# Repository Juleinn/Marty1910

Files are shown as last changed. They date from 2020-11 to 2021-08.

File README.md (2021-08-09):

# Marty 1910 bluetooth interface firmware

This repository stores the firmware for getting old marty 1910 phones back to life with a ag1171 and bm64 modules (SLIC and Bluetooth modules).

- Vidéo :   
Marty 1910 restoration video (https://www.youtube.com/watch?v=Hyl_VwFzOQQ)
- Hackaday.io : [Marty 1910 adapter](https://hackaday.io/project/181056-marty-1910-magneto-phone-bluetooth-adapter)

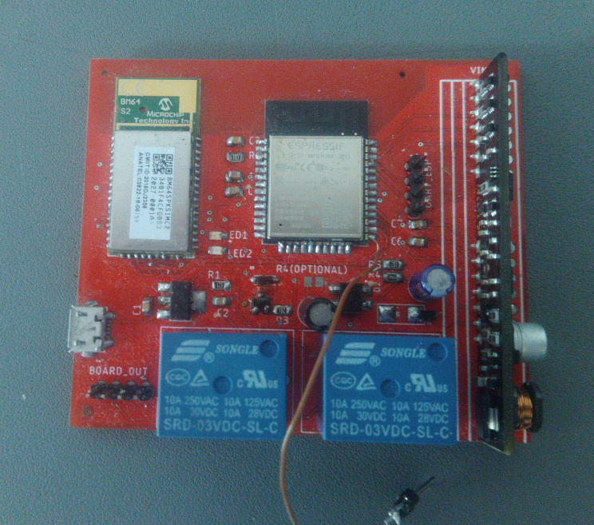
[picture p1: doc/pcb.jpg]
PCB


## Contents
<!-- vim-markdown-toc GitLab -->

* [requirements](#requirements)
* [Configuring the BM64 module](#configuring-the-bm64-module)
* [directory structure](#directory-structure)
* [Firmware description](#firmware-description)

<!-- vim-markdown-toc -->

## requirements
- esp-idf : https://docs.espressif.com/projects/esp-idf/en/latest/esp32/get-started/index.html#installation-step-by-step
- ftdi (for flashing and install)

## Configuring the BM64 module
The BM64 modules requires configuration prior to using it. The configuration process is detailed here : https://github.com/danjulio/blue_pot#bm64-configuration, and this project works with the exact same BM64 configuration as the Blue POT project.

## directory structure
```bash
tree main
main
├── ag1171_driver.c // SLIC driver, including RING signal generation & hangup detection
├── ag1171_driver.h
├── bm64_driver.c // BM64 driver : incomming call events, place calls, ...
├── bm64_driver.h
├── bm64_strings.h
├── CMakeLists.txt
├── component.mk
├── firmware_main.c // main logic
├── line.c  // cranking detection and line relay driving
└── line.h
```

```bash
tree hardware
hardware
├── bluetooth.brd # PCB design
├── bluetooth.csv # list of components
└── bluetooth.sch # schematic
```

## Firmware description

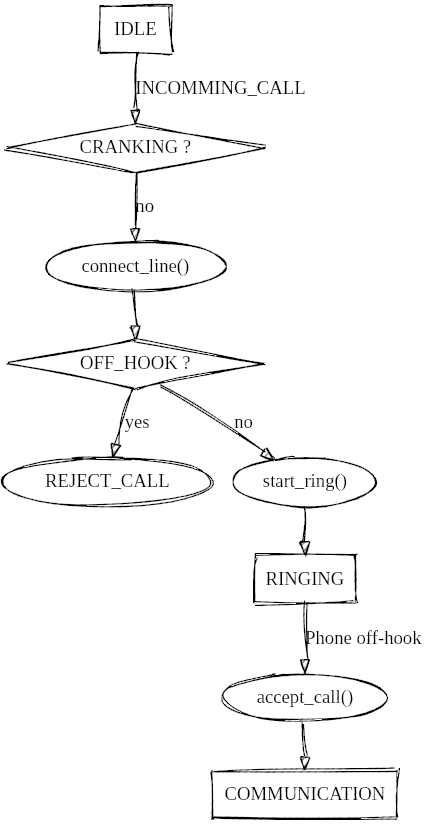
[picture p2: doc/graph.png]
firmware_flowchart


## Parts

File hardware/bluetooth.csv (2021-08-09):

Part | Value | Device | Package | Description | CENTROID_NOT_SPECIFIED | DATASHEET | DC_BLOCKING_VOLTAGE | DEVICE_CLASS_L1 | DEVICE_CLASS_L2 | DEVICE_CLASS_L3 | DIGIKEY_DESCRIPTION | DIGIKEY_PART_NUMBER | FOOTPRINT_URL | FOOTPRINT_VARIANT_NAME_0 | FORWARD_CURRENT | HEIGHT | LEAD_FREE | MAX_REPETITIVE_REVERSE_VOLTAGE | MAX_SURGE_FORWARD_CURRENT | MF | MFG_PACKAGE_IDENT | MFG_PACKAGE_IDENT_DATE | MFG_PACKAGE_IDENT_REV | MOUSER_DESCRIPTION | MOUSER_PART_NUMBER | MPN | OC_FARNELL | OC_NEWARK | PACKAGE | PEAK_REVERSE_CURRENT | POPULARITY | PREFIX | PROD_ID | REVERSE_VOLTAGE | ROHS | SPICEPREFIX | STANDOFF_HEIGHT | TEMPERATURE_RANGE_HIGH | TEMPERATURE_RANGE_LOW | VALUE | VERIFICATION_VERSION | WORKING_REVERSE_VOLTAGE
BM64 |  | DJD_EAGLE_LIBRARY_BM64 | DJD_EAGLE_LIBRARY_BM64 | Microchip BM64 Bluetooth Module
BOARD_OUT |  | MA04-1 | MA04-1 | PIN HEADER |  |  |  |  |  |  |  |  |  |  |  |  |  |  |  |  |  |  |  |  |  |  | unknown | unknown |  |  | 41
C1 | 100nF | C-EUC0805 | C0805 | CAPACITOR, European symbol |  |  |  |  |  |  |  |  |  |  |  |  |  |  |  |  |  |  |  |  |  |  |  |  |  |  | 88 |  |  |  |  | C
C2 | 10uF | C-EUC0805 | C0805 | CAPACITOR, European symbol |  |  |  |  |  |  |  |  |  |  |  |  |  |  |  |  |  |  |  |  |  |  |  |  |  |  | 88 |  |  |  |  | C
C3 | 100nF | C-EUC0805 | C0805 | CAPACITOR, European symbol |  |  |  |  |  |  |  |  |  |  |  |  |  |  |  |  |  |  |  |  |  |  |  |  |  |  | 88 |  |  |  |  | C
C4 | 10uF | C-EUC0805 | C0805 | CAPACITOR, European symbol |  |  |  |  |  |  |  |  |  |  |  |  |  |  |  |  |  |  |  |  |  |  |  |  |  |  | 88 |  |  |  |  | C
C5 | 0.1uF | C-EUC0805 | C0805 | CAPACITOR, European symbol |  |  |  |  |  |  |  |  |  |  |  |  |  |  |  |  |  |  |  |  |  |  |  |  |  |  | 88 |  |  |  |  | C
C6 | 100nF | C-USC0805 | C0805 | CAPACITOR, American symbol
C7 | 10nF | C-USC0805 | C0805 | CAPACITOR, American symbol
C8 |  | CPOL-USE2-5 | E2-5 | POLARIZED CAPACITOR, American symbol
C9 | 10uF | 10UF-POLAR-RADIAL-2.5MM-25V-20% | CPOL-RADIAL-2.5MM-5MM | 10.0µF polarized capacitors |  |  |  |  |  |  |  |  |  |  |  |  |  |  |  |  |  |  |  |  |  |  |  |  |  |  |  |  | CAP-08440 |  |  |  |  |  |  | 10uF
D1 |  | DIODESMA | SMADIODE | Diode
D2 | DIODES_HD04-TDIODES_HD04-T_0_0 | DIODES_HD04-TDIODES_HD04-T_0_0 | DIODES_HD04-T_0 | 0.8A SURFACE MOUNT GLASS PASSIVATED BRIDGE RECTIFIER | No | https://www.diodes.com/assets/Datasheets/ds17003.pdf | 400V | Discrete Semiconductors | Diodes | Rectifier Diodes | DIODE RECT BRIDGE GP 400V 0.8A MINIDIP | HD04DICT-ND | https://www.diodes.com/assets/Package-Files/MiniDIP.pdf | Recommended_Land_Pattern | 0.8A | 3mm | yes | 400V | 30A | Diodes | MiniDIP | 06/2017 | 0 | Bridge Rectifiers 400V 0.8A | 621-HD04T | HD04-T |  |  | MiniDIP-4 | 500uA |  | D |  | 280V | yes |  | 0.2mm | +150°C | -55°C |  | 0.0.0.1 | 400V
D3 |  | DIODESOD-123 | SOD-123 | Diode
IC1 | LD117AS33TR | LD117AS33TR | SOT223 | Low drop fixed and adjustable positive voltage regulators 1 A |  |  |  |  |  |  |  |  |  |  |  |  |  |  |  |  |  |  |  |  |  |  |  |  |  |  | 9
K1 | G5LE | G5LE | G5LE | RELAY |  |  |  |  |  |  |  |  |  |  |  |  |  |  |  |  |  |  |  |  |  |  | unknown | unknown |  |  | 13
K2 | G5LE | G5LE | G5LE | RELAY |  |  |  |  |  |  |  |  |  |  |  |  |  |  |  |  |  |  |  |  |  |  | unknown | unknown |  |  | 13
LED1 |  | LEDCHIP-LED0805 | CHIP-LED0805 | LED
LED2 |  | LEDCHIP-LED0805 | CHIP-LED0805 | LED
R1 | 120 | R-EU_M0805 | M0805 | RESISTOR, European symbol |  |  |  |  |  |  |  |  |  |  |  |  |  |  |  |  |  |  |  |  |  |  |  |  |  |  | 45 |  |  |  |  | R
R2 | 10k | R-EU_M0805 | M0805 | RESISTOR, European symbol |  |  |  |  |  |  |  |  |  |  |  |  |  |  |  |  |  |  |  |  |  |  |  |  |  |  | 45 |  |  |  |  | R
R3 | 1K | R-US_M0805 | M0805 | RESISTOR, American symbol
R4 | 1k | R-US_M0805 | M0805 | RESISTOR, American symbol
R4(OPTIONAL) | 1K | R-US_M0805 | M0805 | RESISTOR, American symbol
R5 | 57k | R-US_M0805 | M0805 | RESISTOR, American symbol
T1 |  | -NPN-SOT23-EBC | SOT23-EBC | NPN Transistror |  |  |  |  |  |  |  |  |  |  |  |  |  |  |  |  |  |  |  |  |  |  |  |  |  |  | 0
U$1 | ESP32-WROOM | ESP32-WROOM | ESP32-WROOM
U$2 | MICRO-USB-RECEPTACLE47589-0001 | MICRO-USB-RECEPTACLE47589-0001 | 47589-0001 | MICRO USB RECEPTACLES
UART_ESP |  | MA04-1 | MA04-1 | PIN HEADER |  |  |  |  |  |  |  |  |  |  |  |  |  |  |  |  |  |  |  |  |  |  | unknown | unknown |  |  | 41
VIN |  | DJD_EAGLE_LIBRARY_AG1171SIL | DJD_EAGLE_LIBRARY_AG1171 | Silvertel AG1171 +3.3V / +5.0V Low Power Ringing SLIC

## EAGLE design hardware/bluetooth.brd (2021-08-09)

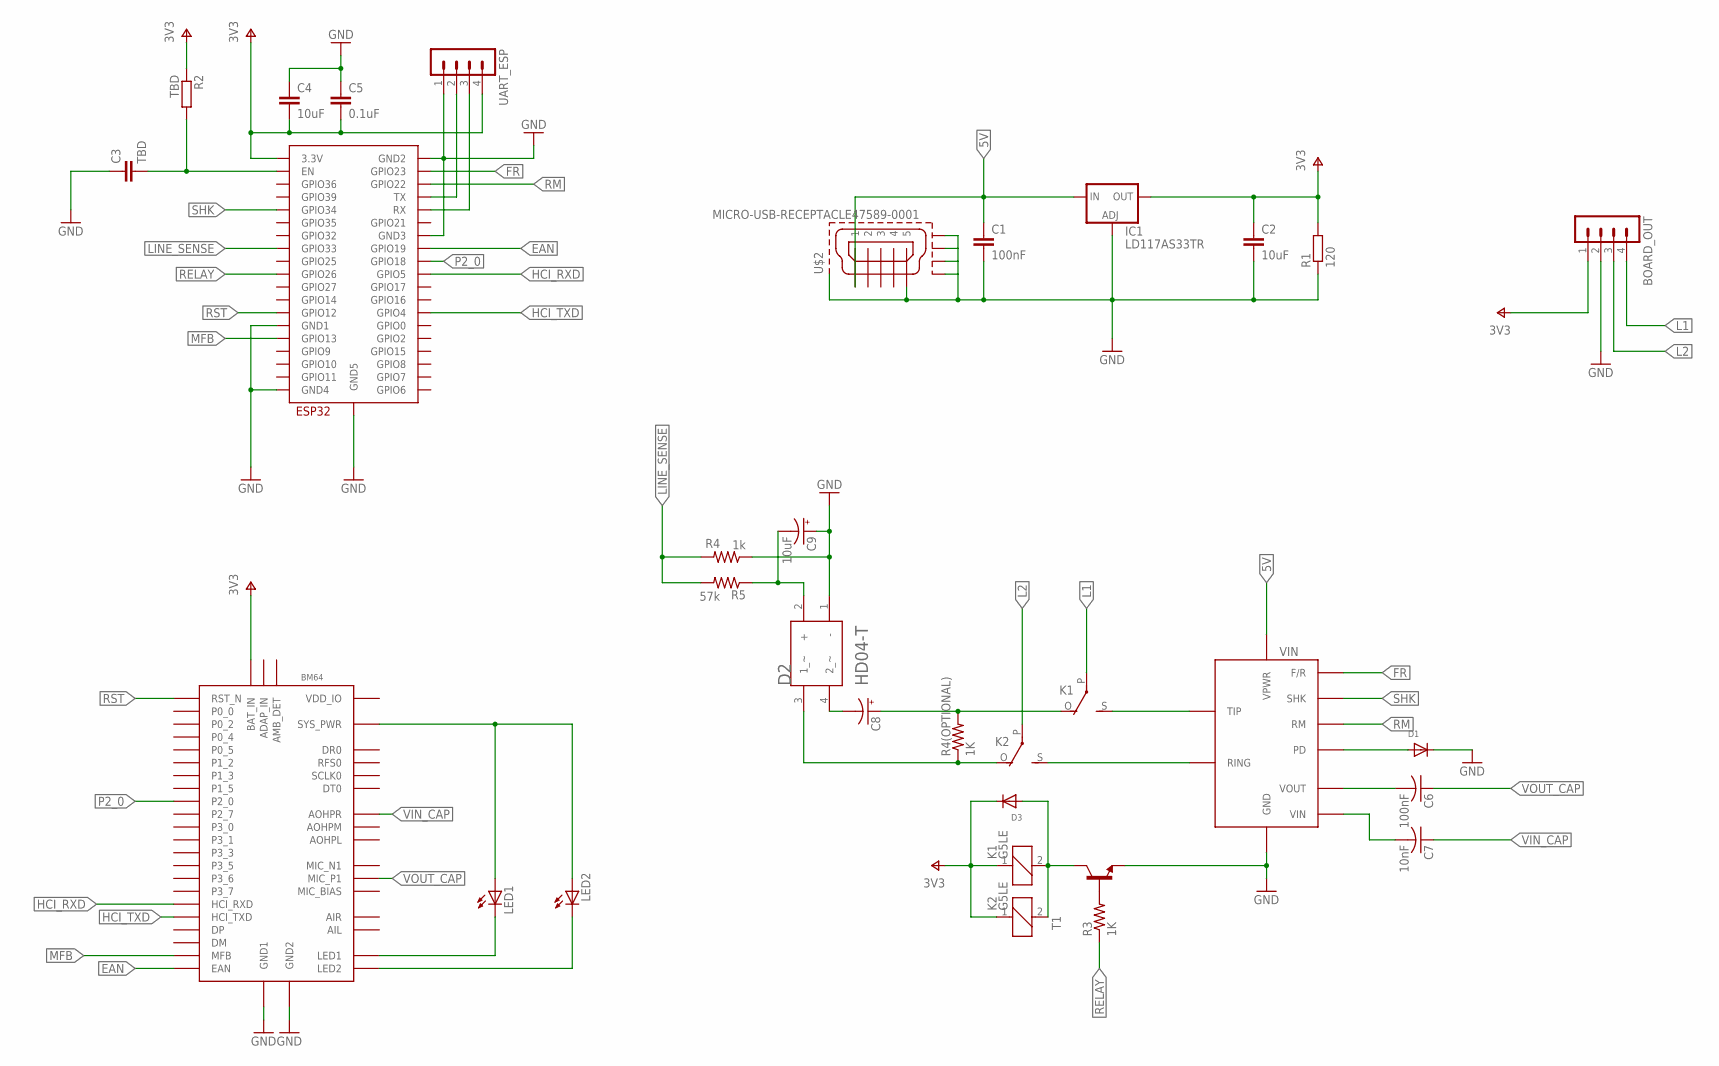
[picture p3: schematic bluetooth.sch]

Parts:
BM64: DJD_EAGLE_LIBRARY_BM64
BOARD_OUT: MA04-1
C1, C6: 100nF; C0805
C2, C4: 10uF; C0805
C3: TBD; C0805
C5: 0.1uF; C0805
C7: 10nF; C0805
C8: CPOL-USE2-5; E2-5
C9: 10uF; CPOL-RADIAL-2.5MM-5MM
D1: DIODESMA; SMADIODE
D2: DIODES_HD04-TDIODES_HD04-T_0_0; DIODES_HD04-T_0
D3: DIODESOD-123; SOD-123
IC1: LD117AS33TR; SOT223
K1, K2: G5LE
LED1, LED2: LEDCHIP-LED0805; CHIP-LED0805
R1: 120; M0805
R2: TBD; M0805
R3, R4(OPTIONAL): 1K; M0805
R4: 1k; M0805
R5: 57k; M0805
T1: -NPN-SOT23-EBC; SOT23-EBC
U$1: ESP32-WROOM
U$2: MICRO-USB-RECEPTACLE47589-0001; 47589-0001
UART_ESP: MA04-1
VIN: DJD_EAGLE_LIBRARY_AG1171SIL; DJD_EAGLE_LIBRARY_AG1171

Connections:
5V: C1.1, IC1.3 (IN), U$2.1, VIN.P$13 (VPWR)
ADAP_IN: BM64.23 (ADAP_IN)
CRANK_LOAD_1: C8.+, K1.O, R4(OPTIONAL).2
CRANK_LOAD_2: D2.3 (1_~), K2.O, R4(OPTIONAL).1
EAN: BM64.32 (EAN), U$1.IO19 (GPIO19)
ESP_EN: C3.2, R2.2, U$1.EN
ESP_RX: U$1.RX, UART_ESP.3
ESP_TX: U$1.TX, UART_ESP.2
FR: U$1.IO23 (GPIO23), VIN.P$3 (F/R)
GND: BM64.14 (GND1), BM64.43 (GND2), BOARD_OUT.2, C1.2, C2.2, C3.1, C4.1, C5.1, C9.1 (+), D1.C, D2.1 (-), IC1.1 (ADJ), R1.1, R4.1, T1.E, U$1.GND1, U$1.GND2, U$1.GND3, U$1.GND4, U$1.GND5, U$2.5, U$2.CASING1 (GND1), U$2.CASING2 (GND2), U$2.CASING3 (GND3), U$2.CASING4 (GND4), UART_ESP.1, VIN.P$12 (GND)
HCI_RXD: BM64.19 (HCI_RXD), U$1.IO5 (GPIO5)
HCI_TXD: BM64.20 (HCI_TXD), U$1.IO4 (GPIO4)
L1: BOARD_OUT.4, K1.P
L2: BOARD_OUT.3, K2.P
LED1: BM64.28 (LED1), LED1.C
LED2: BM64.27 (LED2), LED2.C
LINE_RELAY_1: K1.S, VIN.P$2 (TIP)
LINE_RELAY_2: K2.S, VIN.P$1 (RING)
LINE_SENSE: R4.2, R5.2, U$1.IO33 (GPIO33)
MFB: BM64.26 (MFB), U$1.IO13 (GPIO13)
unnamed: R3.2, T1.B
unnamed: C8.-, D2.4 (2_~)
unnamed: C9.2 (-), D2.2 (+), R5.1
P2_0: BM64.41 (P2_0), U$1.IO18 (GPIO18)
POWER_DOWN: D1.A, VIN.P$14 (PD)
RELAY: R3.1, U$1.IO26 (GPIO26)
RELAY_DRIVE: D3.A, K1.2, K2.2, T1.C
RM: U$1.IO22 (GPIO22), VIN.P$4 (RM)
RST: BM64.13 (RST_N), U$1.IO12 (GPIO12)
SHK: U$1.IO34 (GPIO34), VIN.P$5 (SHK)
SYS_PWR: BM64.24 (SYS_PWR), LED1.A, LED2.A
V+: BM64.22 (BAT_IN), BOARD_OUT.1, C2.1, C4.2, C5.2, D3.C, IC1.4 (OUT), K1.1, K2.1, R1.2, R2.1, U$1.3V3 (3.3V), UART_ESP.4
VIN: C7.2, VIN.P$9 (VIN)
VIN_CAP: BM64.5 (AOHPR), C7.1
VOUT: C6.2, VIN.P$10 (VOUT)
VOUT_CAP: BM64.9 (MIC_P1), C6.1

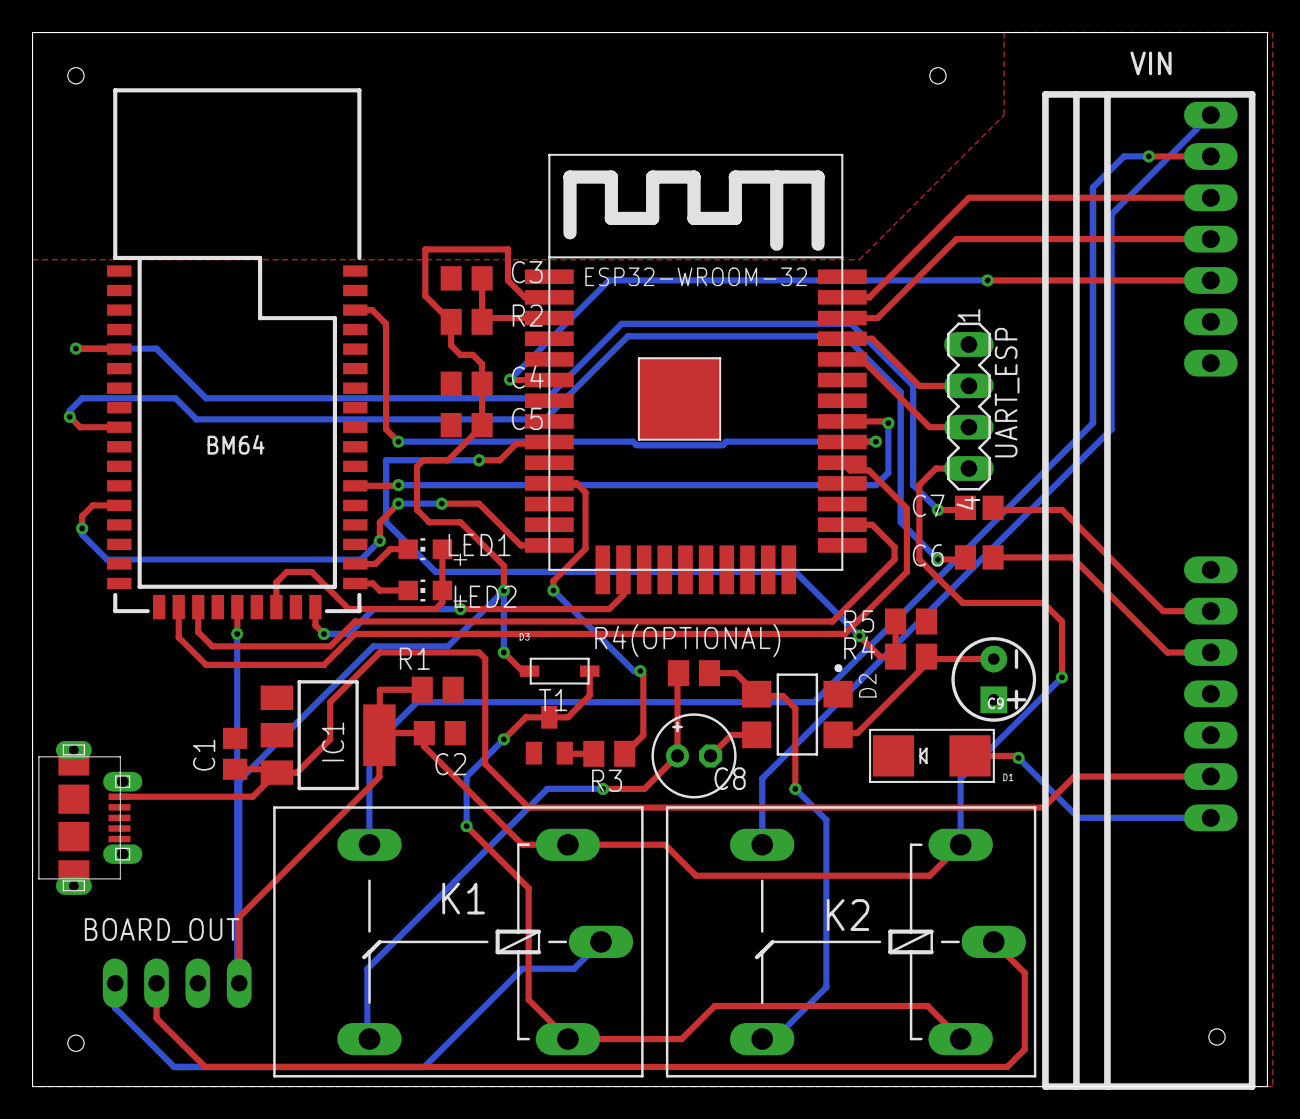
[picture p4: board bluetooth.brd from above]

Board: 2 copper layers, 75.9 x 64.8 mm, 30 parts (1 on the bottom side), 35 nets.

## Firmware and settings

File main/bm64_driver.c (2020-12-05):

#include "driver/gpio.h"
#include "driver/uart.h"
#include "bm64_driver.h"
#include <stdio.h>
#include <string.h>
#include "endian.h"

#include "freertos/FreeRTOS.h"
#include "freertos/task.h"

#define P2_0        18
#define EAN         19
#define MFB         13
#define RST         12
#define GPIO_OUTPUT_PIN_SEL  ((1ULL<<P2_0) | (1ULL<<EAN) | (1ULL<<MFB) | (1ULL<<RST))

// uart config
#define UART_PORT_NUMBER 2
#define UART_SPEED       115200
#define UART_RXD_PIN     4
#define UART_TXD_PIN     5
#define UART_BUF_SIZE    1024

uart_config_t uart_config = {
    .baud_rate = UART_SPEED,
    .data_bits = UART_DATA_8_BITS,
    .parity    = UART_PARITY_DISABLE,
    .stop_bits = UART_STOP_BITS_1,
    .flow_ctrl = UART_HW_FLOWCTRL_DISABLE,
    .source_clk = UART_SCLK_APB,
};

static void bm64_uart_init()
{
#if CONFIG_UART_ISR_IN_IRAM
    intr_alloc_flags = ESP_INTR_FLAG_IRAM;
#endif

    ESP_ERROR_CHECK(uart_driver_install(UART_PORT_NUMBER, UART_BUF_SIZE * 2, 0, 0, NULL, 0));
    ESP_ERROR_CHECK(uart_param_config(UART_PORT_NUMBER, &uart_config));
    ESP_ERROR_CHECK(uart_set_pin(UART_PORT_NUMBER, UART_TXD_PIN, UART_RXD_PIN, 0, 0));

}

static void bm64_reset(void)
{
    gpio_set_level(MFB, 0);
    gpio_set_level(RST, 0);
    vTaskDelay(499 / portTICK_RATE_MS);

    gpio_set_level(MFB, 1);

    vTaskDelay(1 / portTICK_RATE_MS);

    gpio_set_level(RST, 1);
}

static void bm64_gpio_init()
{
    gpio_config_t io_conf;
    //disable interrupt
    io_conf.intr_type = GPIO_INTR_DISABLE;
    //set as output mode
    io_conf.mode = GPIO_MODE_OUTPUT;
    //bit mask of the pins that you want to set,e.g.GPIO18/19
    io_conf.pin_bit_mask = GPIO_OUTPUT_PIN_SEL;
    //disable pull-down mode
    io_conf.pull_down_en = 0;
    //disable pull-up mode
    io_conf.pull_up_en = 0;
    //configure GPIO with the given settings
    gpio_config(&io_conf);

    gpio_set_level(P2_0, 1);
    gpio_set_level(EAN, 0);
    gpio_set_level(MFB, 1);
    gpio_set_level(RST, 1);
}

void bm64_prepare_flash_mode()
{
    bm64_gpio_init();
    gpio_set_level(P2_0, 0);
    gpio_set_level(EAN, 0);
    bm64_reset();
}

static void bm64_ack_event(uint8_t event);

static uint8_t compute_checksum(uint8_t *data, int length)
{
    int i=0;
    uint8_t res = 0;
    for(i=0;i<length;i++)
    {
        res += data[i];
    }

    return (~res) + 1;
}

typedef struct EventHeader {
    //0x00 0xAA 0x00 0x03 0x00 0x05 0x00 0xF8
    uint16_t preamble;
    uint16_t length;
    uint8_t event_code;
} __attribute__((packed)) EventHeader ;

typedef enum EventType {
    ACK             = 0x00,
    BTM_STATUS      = 0x01,
    CALL_STATUS     = 0x02,
	CALLER_ID	    = 0x03,
    PHONE_CURRENT_BATTERY_LEVEL = 0x07,
} EventType;

typedef enum MMIAction {
    ACCEPT_CALL = 0x04,
    REJECT_CALL = 0x05,
    END_CALL = 0x02,
} __attribute__((packed)) MMIAction;

typedef struct MMIActionPayload {
    uint8_t data_base_index;
    uint8_t action;
} __attribute__((packed)) MMIActionPayload;

typedef struct Ack {
    uint8_t opcode;
    uint8_t status;
} __attribute__((packed)) Ack;

typedef struct CallStatus {
    uint8_t data_base_index;
    uint8_t call_status;
} __attribute__((packed)) CallStatus;

typedef struct BTMStatus {
    uint8_t status;
} __attribute__((packed)) BTMStatus;

typedef struct __attribute__((packed)) PhoneBatteryLevel {
    uint8_t data_base_index;
    uint8_t battery_level;
} PhoneBatteryLevel;

typedef struct Event {
    EventType type;
    union data {
        struct Ack ack;
    };
} Event;

/* Static definitions */
static void bm64_uart_init();
static void bm64_reset(void);
static void bm64_gpio_init();
static int bm64_send_command(uint8_t opcode, uint8_t * data, int data_len, uint8_t *destination, int *dest_len);

static int bm64_wait_event_buffer(uint8_t * buf, int * read_len)
{
    int len = uart_read_bytes(UART_PORT_NUMBER, buf, sizeof(EventHeader), 200 / portTICK_RATE_MS);
    if(len < sizeof(EventHeader))
    {
        return BM64_DATA_TOOSHORT;
    }
    EventHeader header;
    memcpy(&header, buf, sizeof(header));

    header.length = bswap16(header.length);

    // read length more bytes+checksum
    len = len + uart_read_bytes(UART_PORT_NUMBER, 
            buf+len, // offset
            header.length, // length of data + checksum
            0);
    if(len < sizeof(EventHeader) + header.length)
    {
        return BM64_DATA_TOOSHORT;
    }

    *read_len = len;

    return BM64_NOERROR;
}

#include "bm64_strings.h"

static int bm64_wait_event(Event * evt)
{
    uint8_t buf[UART_BUF_SIZE];
    int read_len = 0;
    int err = bm64_wait_event_buffer(buf, &read_len);
    if(err != BM64_NOERROR)
    {
        return err;
    }

    EventHeader * header = (EventHeader*) buf;     
    printf("Event : %s\n", EVENT_NAMES[header->event_code]);
    switch(header->event_code)
    {
        case ACK:
            evt->type = ACK;
            Ack ack;
            memcpy(&ack, buf+sizeof(EventHeader), sizeof(ack));
            printf("ACK opcode %d status %d\n", ack.opcode, ack.status);
            break;

        case BTM_STATUS:
            {
                BTMStatus * status = (BTMStatus*) (buf+sizeof(EventHeader)); 
                printf("BTM Status : %s\n", BTM_STATUSES[status->status]);

                evt->type = BTM_STATUS;
                break;
            };

        case CALL_STATUS:
            {
                CallStatus cs;
                cs.data_base_index = buf[sizeof(EventHeader)];
                cs.call_status = buf[sizeof(EventHeader)+sizeof(cs.data_base_index)];
                printf("Call status : %s\n", CALL_STATUSES[cs.call_status]);
                if(cs.call_status == CALL_STATUS_INCOMMING_CALL) 
                {
                    bm64_on_incomming_call();
                }
                if(cs.call_status == CALL_STATUS_IDLE)
                {
                    bm64_on_call_status_idle();
                }
                if(cs.call_status == CALL_STATUS_OUTGOING_CALL)
                {
                    bm64_on_outgoing_call();
                }

                break;
            };
        case CALLER_ID:
            {
                buf[read_len] = '\0';
                printf("Caller ID : %s\r\n", &buf[sizeof(EventHeader) + 1]);
                break;
            };

        case PHONE_CURRENT_BATTERY_LEVEL:
            {
                PhoneBatteryLevel * bl = (PhoneBatteryLevel*) buf+sizeof(EventHeader);
                printf("Phone battery level = %d/220\n", bl->battery_level);

                break;
            };
        default:
            break;
    }
    // acknowldge the event to speed up processing 
    bm64_ack_event(header->event_code);
    printf("\n");
    return BM64_NOERROR;
}
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

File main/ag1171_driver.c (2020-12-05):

#include "ag1171_driver.h"
#include "driver/gpio.h"
#include "driver/uart.h"
#include "freertos/FreeRTOS.h"
#include "freertos/task.h"
#include "freertos/queue.h"

#define RM 22
#define FR 23
#define SHK 34

#define GPIO_OUTPUT_PIN_SEL ((1ULL << RM) | (1ULL << FR))
#define GPIO_INPUT_PIN_SEL ((1ULL << SHK))
#define ESP_INTR_FLAG_DEFAULT 0

static xQueueHandle gpio_evt_queue = NULL;
static void IRAM_ATTR ag1171_shk_isr_handler(void* args)
{
    uint32_t value = 0;
    xQueueSendFromISR(gpio_evt_queue, &value, NULL);
}


static void ag1171_ring_task();

void __attribute__((weak)) ag1171_on_phone_offhook()
{
    printf("Phone gone off-hook (weak)\n");
}

void __attribute__((weak)) ag1171_on_phone_onhook()
{
    printf("Phone gone on-hook (weak)\n");
}

static void ag1171_task(void* arg)
{
    uint32_t last_value = 0;
    for(;;) {
        uint32_t value1 = gpio_get_level(SHK); 
        if(value1 != last_value) 
        {
            vTaskDelay(15 / portTICK_RATE_MS); // ag1171 doc recommends >= 10ms
            uint32_t value2 = gpio_get_level(SHK); 
            if(value1 == value2)
            {
                if(value1)
                {
                    printf("Phone off-hook\n");
                    ag1171_on_phone_offhook();
                }
                else
                {
                    printf("Phone on-hook\n");
                    ag1171_on_phone_onhook();
                }
                last_value = value1;
            }

        }
        vTaskDelay(15 / portTICK_RATE_MS); // Lets not loop around too fast
    }
}

bool ag1171_is_offhook()
{
    return gpio_get_level(SHK);
}

void ag1171_init()
{
    printf("portTICK_RATE_MS : %d\n", portTICK_RATE_MS);
    gpio_config_t io_conf;

    // output config
    io_conf.intr_type = GPIO_INTR_DISABLE;
    io_conf.pin_bit_mask = GPIO_OUTPUT_PIN_SEL;
    io_conf.pull_down_en = 0;
    io_conf.mode = GPIO_MODE_OUTPUT;
    io_conf.pull_up_en = 0;
    gpio_config(&io_conf);

    gpio_set_level(FR, 1);
    gpio_set_level(RM, 0);

    // input config
    io_conf.pin_bit_mask = GPIO_INPUT_PIN_SEL;
    io_conf.mode = GPIO_MODE_INPUT;
    io_conf.intr_type = GPIO_INTR_ANYEDGE;
    io_conf.pull_down_en = 1;
    gpio_config(&io_conf);

    gpio_evt_queue = xQueueCreate(1, sizeof(uint32_t));
    //start gpio task
    xTaskCreate(ag1171_task, "ag1171_task", 2048, NULL, 10, NULL);

    gpio_install_isr_service(ESP_INTR_FLAG_DEFAULT);
    gpio_isr_handler_add(SHK, ag1171_shk_isr_handler, NULL); 
}

void ring_once()
{
    gpio_set_level(RM, 1);

    int i;
    for(i=0;i<20;i++)
    {
        // 25ms * 2 = 50ms = 20Hz (ring tone freq from original Marty 1910 phones)
        gpio_set_level(FR, 0);
        vTaskDelay(25 / portTICK_RATE_MS);
        gpio_set_level(FR, 1);
        vTaskDelay(25 / portTICK_RATE_MS);
    }
    
    // ag1171 datasheet recommends wait >10ms after FR back to high
    // this is achieved above but for safety lets do it here again
    vTaskDelay(15 / portTICK_RATE_MS);

    gpio_set_level(RM, 0);
}

static volatile bool ringing = false;

void ag1171_start_ringing()
{
    ringing = true;
    xTaskCreate(ag1171_ring_task, "ag1171_ring_task", 2048, NULL, 10, NULL);
}

void ag1171_stop_ringing()
{
    ringing = false;
}

static void ag1171_ring_task()
{
    while(ringing)
    {
        gpio_set_level(RM, 1);

        int i;
        for(i=0;i<20;i++)
        {
            // 25ms * 2 = 50ms = 20Hz (ring tone freq from original Marty 1910 phones)
            gpio_set_level(FR, 0);
            if(!ringing) break; // try to exit as quickly as possible
            vTaskDelay(25 / portTICK_RATE_MS);
            gpio_set_level(FR, 1);
            if(!ringing) break; // try to exit as quickly as possible
            vTaskDelay(25 / portTICK_RATE_MS);
        }

        // ag1171 datasheet recommends wait >10ms after FR back to high
        // this is achieved above but for safety lets do it here again
        vTaskDelay(15 / portTICK_RATE_MS);

        gpio_set_level(RM, 0);

        if(!ringing) break; // try to exit as quickly as possible
        vTaskDelay(3000 / portTICK_RATE_MS);
    }
    vTaskDelete(NULL);
}

void ag1171_ring_short()
{
    // ring 3 times to make sure bells are hit at least 2 times
    // as hammer might be stuck on one side
    // but since we need to go back to FR=1 at the end, needs to be even, so 4
    gpio_set_level(RM, 1);

    int i;
    for(i=0;i<4;i++)
    {
        // 25ms * 2 = 50ms = 20Hz (ring tone freq from original Marty 1910 phones)
        gpio_set_level(FR, 0);
        vTaskDelay(25 / portTICK_RATE_MS);
        gpio_set_level(FR, 1);
        vTaskDelay(25 / portTICK_RATE_MS);
    }

    gpio_set_level(RM, 0);
}

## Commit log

2020-10-04 Split bm64 driver into separate file
2020-10-04 Add event processing & device name change
2020-10-17 Add relay
    - add relay on-off sequence
    - add bm64 commands decoding
2020-11-05 Add ag1171 driver
2020-11-09 Add line (relays) controller
2020-11-11 Add bm64 incomming call callback
    - add weak callback to be overridden to handle incomming call
    - Fix stack overflow on printing bm64 events
    - Fix latency on parsing uart bm64 events
    [bm64_driver.c]
2020-11-11 Fix stack overflow crash (increase stack size)
    [bm64_driver.c]
2020-11-11 Change end call uart command
    End call/transfer audio -> force end call
2020-11-11 Reduce latency of bm64 events
    Acknowledge bm64 commands after processing to prevent it from waiting 800ms timeout before sending the next event. This increases responsivity a lot.
    [bm64_driver.c]
2020-11-12 Fix invalid off-hook detection
    - fix invalid debouncing
    - empty event queues before waiting for new events (removes duplicate events)
    [ag1171_driver.c]
2020-12-05 Change pinout to match PCB
    - Swap UART pins to bm64
    - Swap FR/RM to ag1171
    - Swap relay levels
    [ag1171_driver.c, bm64_driver.c, line.c]
2021-08-09 Add board, schematic and components
    [bluetooth.brd, bluetooth.csv, bluetooth.sch]

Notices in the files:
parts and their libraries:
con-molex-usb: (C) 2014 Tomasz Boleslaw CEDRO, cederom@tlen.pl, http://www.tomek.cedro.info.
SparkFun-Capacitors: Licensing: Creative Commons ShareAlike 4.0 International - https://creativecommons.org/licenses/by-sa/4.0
